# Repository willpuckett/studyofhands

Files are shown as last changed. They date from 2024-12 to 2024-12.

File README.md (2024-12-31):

# Study Of Hands

> Find your optimal column placement.

StudyofHands

## Instructions

Print as many columns/thumbs as you plan to use in your board (col.stl & thumb.stl). 
Poplate them with 6x3mm round magnets, switches, and keycaps. If you find your switches aren't fitting well, it may be a good time to calibrate your [extra inner](https://www.youtube.com/watch?v=1O-Ho47rwLY) settings.

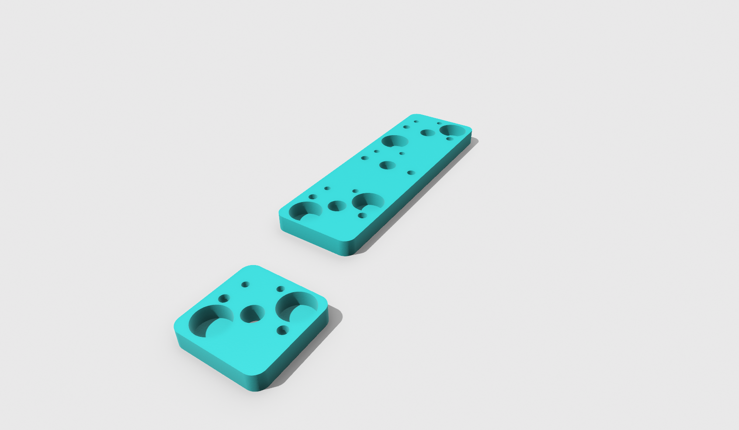
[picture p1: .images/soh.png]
rendering


It's preferable to use the keycaps you plan on using on the final board.
Type on it for a bit, and push and shove till it feels real good.

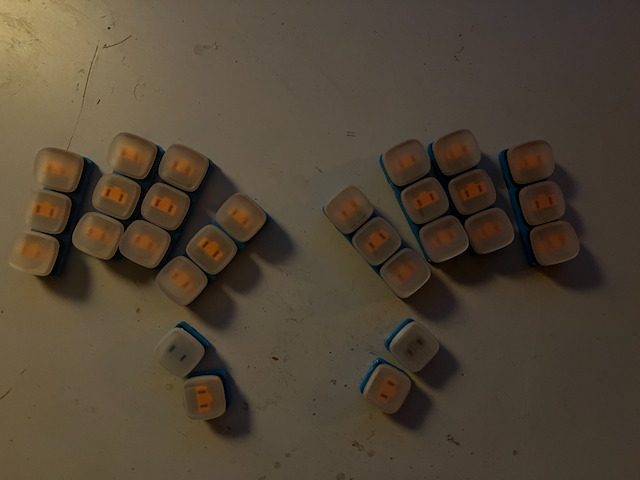
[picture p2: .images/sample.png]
sample


Scan and scale your board in your favorite cad app (shapr3d works well), then import the col and thumb svgs from this project.

Move and rotate the svgs over the keys. 

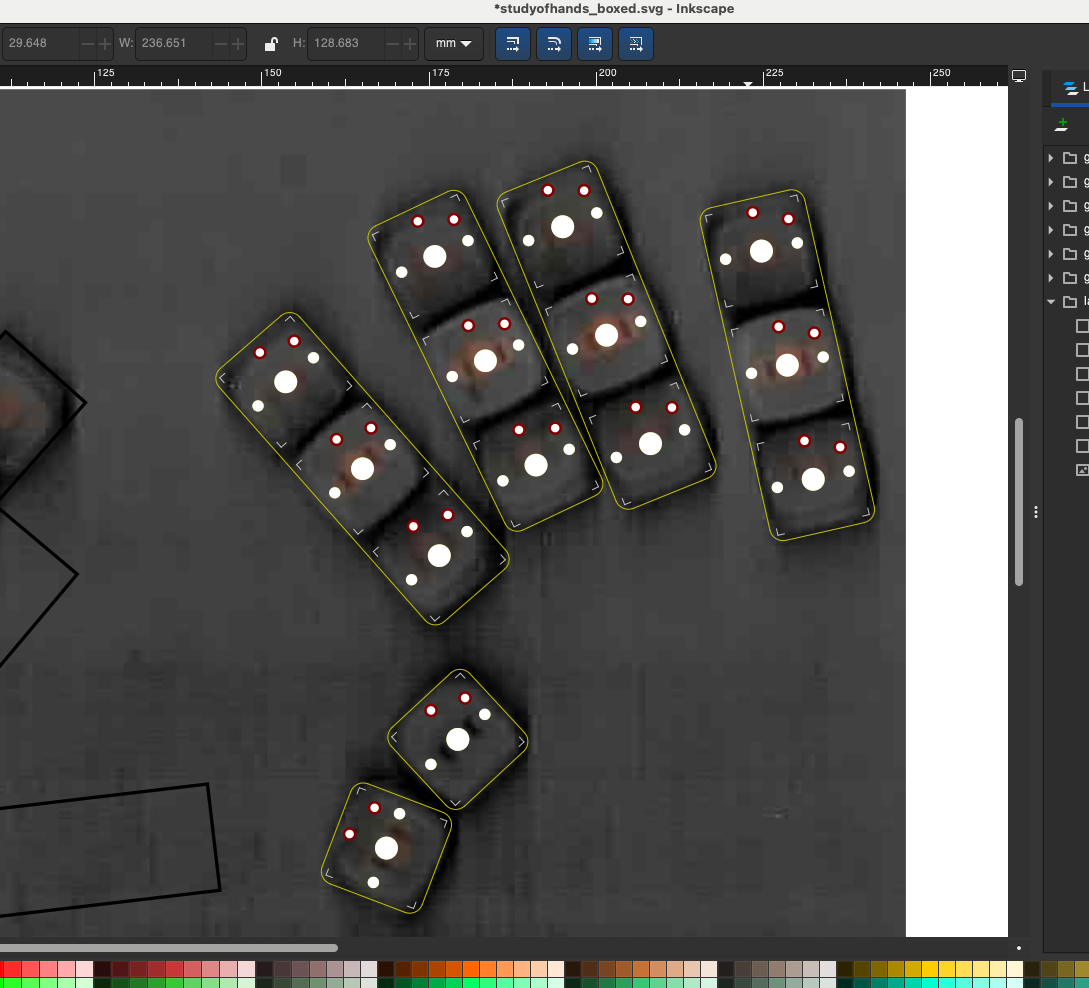
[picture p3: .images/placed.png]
placed


Draw a vertical line beside the pinky column and measure the angle between the two. Double this value for your angle between halves (for monoblocks).

Measuring from the switch outline,

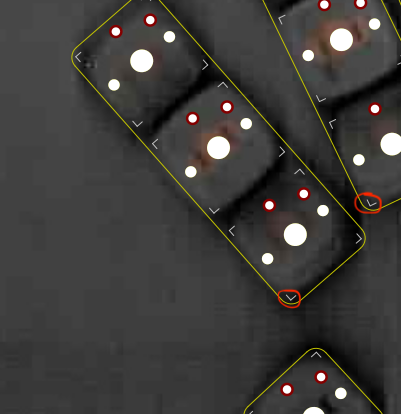
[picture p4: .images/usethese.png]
usethese


 Use your cad package's measure tool to find the spread, stagger, and splay from one column to the next, inputting the numbers in your ergogen config.

### Spread

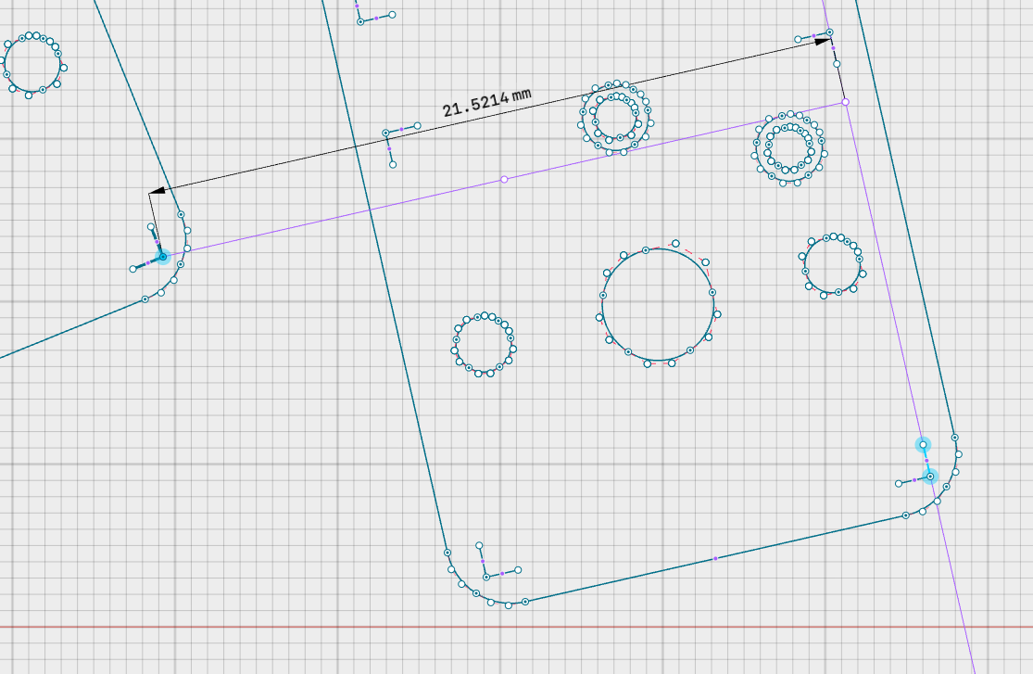
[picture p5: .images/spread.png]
spread


### Stagger

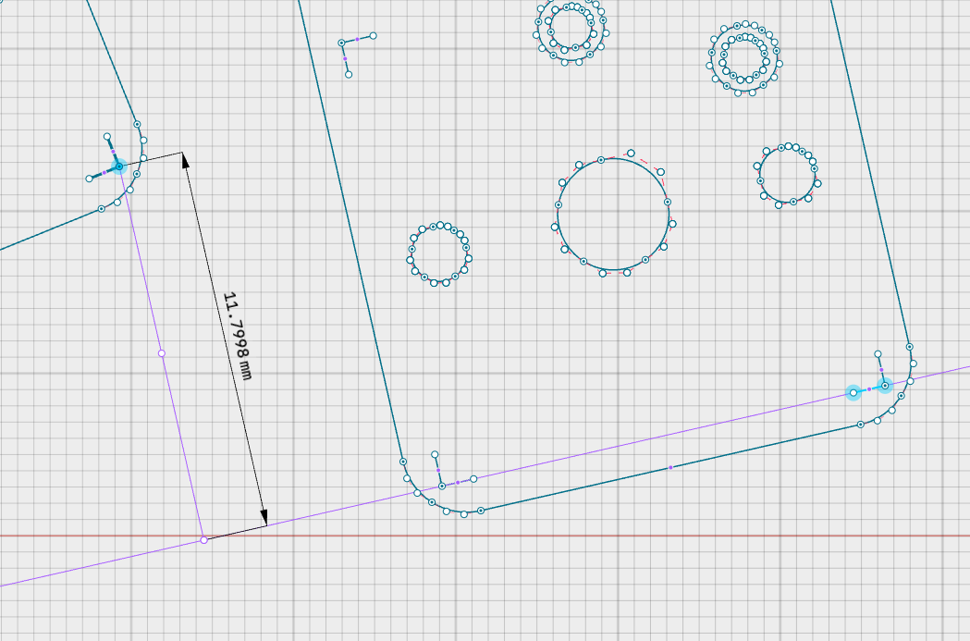
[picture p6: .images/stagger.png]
stagger


### Splay

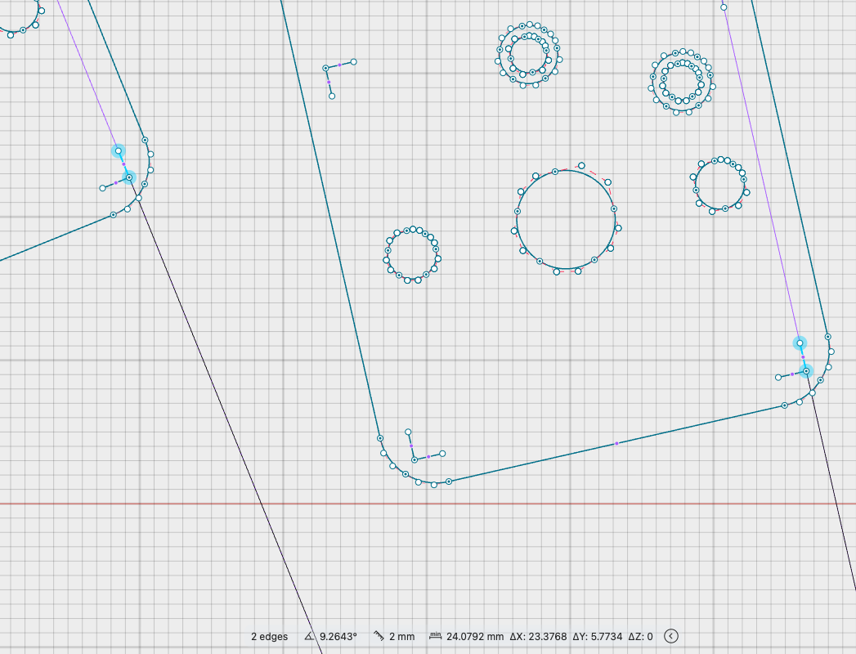
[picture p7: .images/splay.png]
splay


##

It could be interesting to put an mcu on each column and have a really modular board...

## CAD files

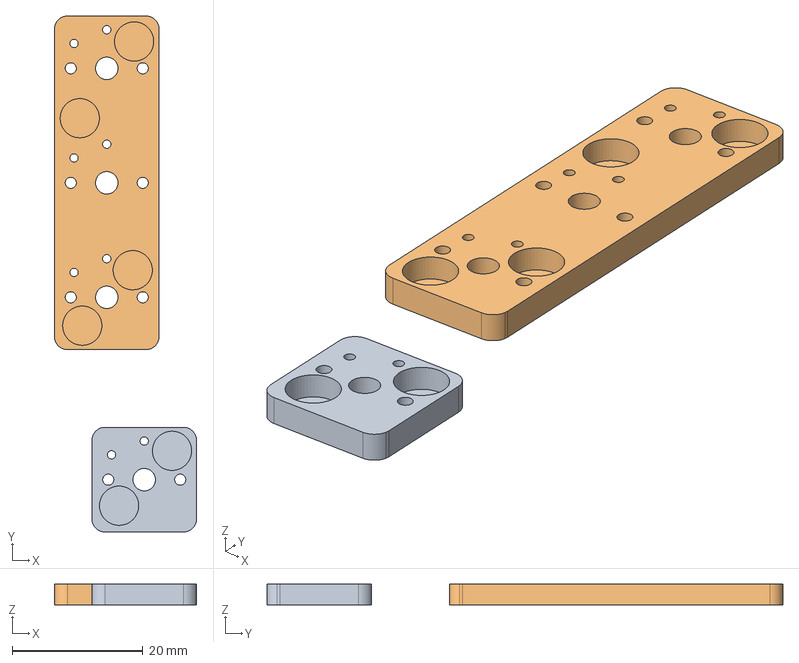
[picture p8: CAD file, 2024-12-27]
studyofhands.step
21.7 x 78.9 x 3.20 mm

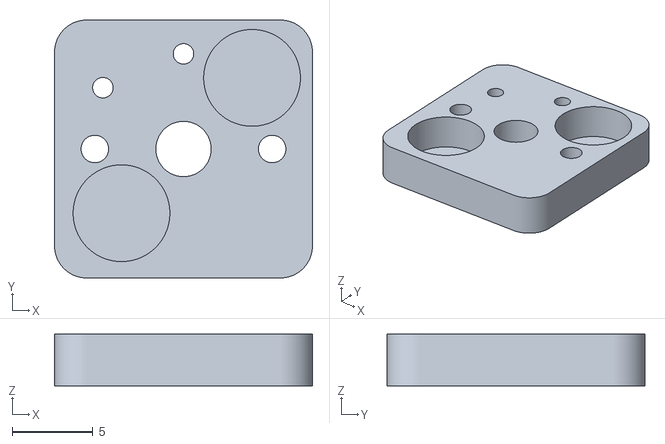
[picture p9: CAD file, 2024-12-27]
thumb.stl
16.0 x 16.0 x 3.20

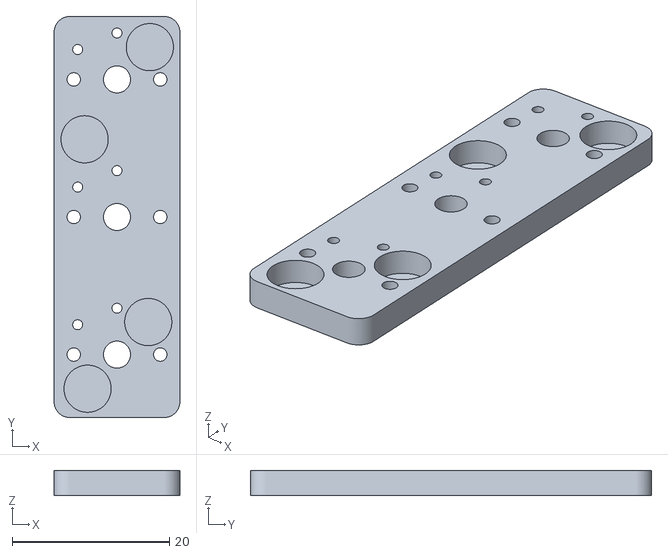
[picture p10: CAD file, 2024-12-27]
col.stl
16.0 x 51.0 x 3.20

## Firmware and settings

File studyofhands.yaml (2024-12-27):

# ergogen --clean studyofhands.yaml

meta:
  engine: 4.1.0
  name: studyofhands
  version: 0.1
  author: willpuckett
  url: https://github.com/willpuckett/studyofhands

presets:
  # These presets provide different layout options
  # Select a preset in the `units` section below
  # Note: The appropriate switch footprint will still need to be set in the `pcb` section
  choc_spaced:
    capx: 17        # Key cap size horizontal
    capy: 16        # Key cap size vertical
    kx: 18.5        # Key spacing horizontal
    ky: 17.5        # Key spacing vertical
    pinky_splay:  8  # Degrees of splay between pinky and ring columns
    pinky_adj: -46   # Adjustment to compensate for splay spacing
    ring_splay: 1
    ring_adj: -12
    middle_splay: 0
    middle_adj: 0
    index_stagger: 0.8ky
    index_splay: -6
    index_adj: -26
    thumb_offsetx: 0.25kx
  
  choc_min_spaced:
    capx: 14.5
    capy: 14.5
    kx: 15.5
    ky: 15.5
    pinky_splay: 5
    pinky_adj: -3
    ring_splay: 3
    ring_adj: -8
    middle_splay: 3
    middle_adj: -5
    thumb_offsetx: 1/3kx

  mx_spaced:
    capx: 18
    capy: 18
    kx: 19
    ky: 19
    pinky_splay: 5
    pinky_adj: -4
    ring_splay: 3
    ring_adj: -10
    middle_splay: 0
    middle_adj: 0
    thumb_offsetx: 0.25kx
  
  mx_min_spaced:
    capx: 15.5
    capy: 15.5
    kx: 16 + 0.5
    ky: 16 + 0.5
    pinky_splay: 5
    pinky_adj: -3
    ring_splay: 3
    ring_adj: -8
    middle_splay: 3
    middle_adj: -5
    thumb_offsetx: 1/3kx

units:
  $extends: presets.choc_spaced
  angle: 22  # Angle between halves

  # Defaults/Constants
  # ====================
  $default_height: 0  # Points invisible by default unless height/width explicitly set
  $default_width: 0
  xiao_x: 17.8
  xiao_y: 21
  sf: 16

points:
  zones.matrix:
    anchor.shift: [100, -100]  # Fix placement on KiCAD sheet
    # rotate: -angle + pinky_splay + ring_splay

    key:
      width: capx
      height: capy
      spread: kx      
      padding: ky
      autobind: 0
    rows:
      bottom:
      home:
      top:
    columns.pinky:
      rows:
        bottom:
          bind: [0.5ky, 0, 0, 0]
        home:
          bind: [0.5ky, 0, 0, 0]
        top:
          bind: [0, 0, 0, 0]
  zones.thumb:
    anchor:
      ref: matrix_pinky_bottom
      shift: [0, -28]
    key.$extends: points.zones.matrix.key
    columns:
      tucky:
outlines:
    _key_outline:
      - what: rectangle
        bound: true
        size: sf
        where:
          - /matrix_.*/
          - /thumb_.*/
    _panel:
        # fillet: 0  # The index rounding where the glue meets the top center keys
      - _key_outline
    panel:
      - name: _panel
        fillet: 2
    _switches:
      - what: rectangle
        size: 14
        where:
          - /matrix_.*/
          - /thumb_.*/
    _keycaps:
      - what: rectangle
        size: [capx, capy]
        where:
          - /matrix_.*/
          - /thumb_.*/
    _mcu:
      - what: rectangle
        where: mcu
        size: [xiao_x, xiao_y]
    demo_keycaps:
      - panel
      - ^_keycaps
      - ^_mcu
pcbs:
  studyofhands:
    outlines:
      main:
        outline: panel
    footprints:
      switches:
        what: choc
        where:
          - /matrix_.*/
          - /thumb_.*/
        params:
          from: GND
          to: "{{name}}"
  
